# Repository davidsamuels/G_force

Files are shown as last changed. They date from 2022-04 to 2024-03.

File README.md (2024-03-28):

# G_force : repository of my passion project involving microcontrollers and motorsports

## hardware chart
prototype | status | notes | picture |
---|---|---| --- | 
version 0 | done | proof of concept in C with arduino dev board | 
version 1 | done | directionality and RGB in C with arduino dev board |
version 2 | done | switching to rasperby pi rp2040  dev board due to chip shortage. Code still being ported. Partial PCB done with manufacturing files and tested |     
version 3| IP | custom PCB with all components. Switching to Esp32 ecosystem due to wifi/BT |  

*prototype version 1 hardware shown below*
---

Acceleration high point of view.

https://user-images.githubusercontent.com/15238565/163253612-991ed954-f6e4-438f-9013-d2a51dcb510f.mp4

Acceleration gauge cluster point of view.
**note colors are not getting picked up by the gopro well**. Look at the 12 and 6 positions on display to see readout.

https://user-images.githubusercontent.com/15238565/163262918-7c1ad50d-a557-4db1-85e5-fd604fd82128.mp4

Demo code showing the crosshair display.

party_mode

Still image of crosshair display



PCB layout screenshot.


3D render of prototype hardware v2


3D render of prototype hardware v3

Back side view


Schematic v3


Layout v3


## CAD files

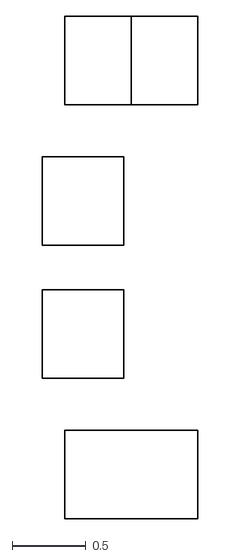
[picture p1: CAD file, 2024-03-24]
gforce_esp32/custom_parts/b3dq_pads.dxf
1.05 x 3.40

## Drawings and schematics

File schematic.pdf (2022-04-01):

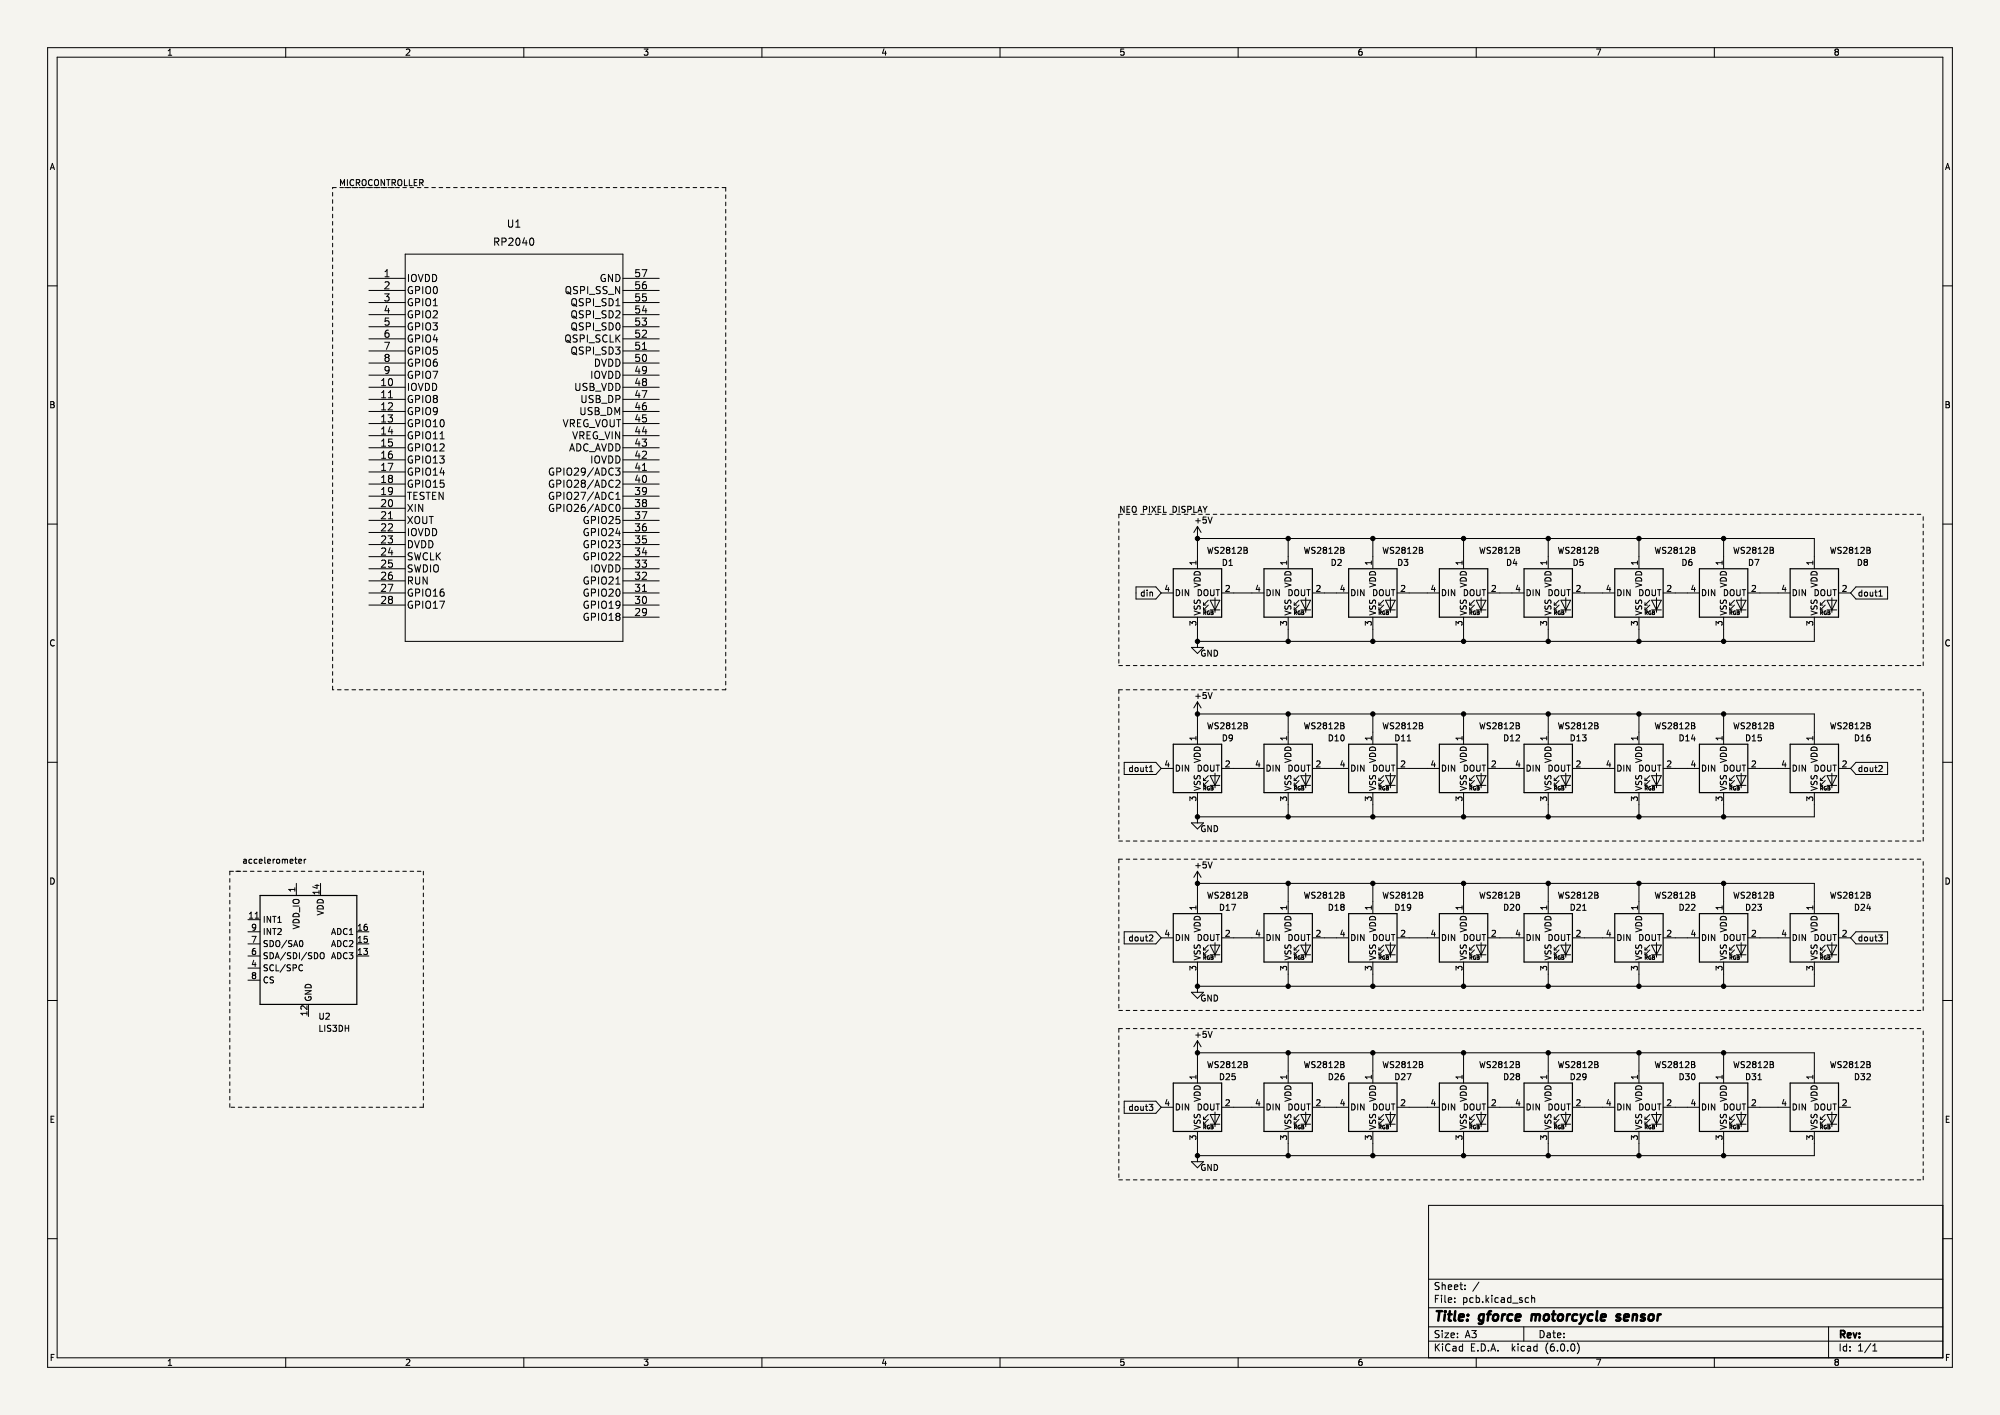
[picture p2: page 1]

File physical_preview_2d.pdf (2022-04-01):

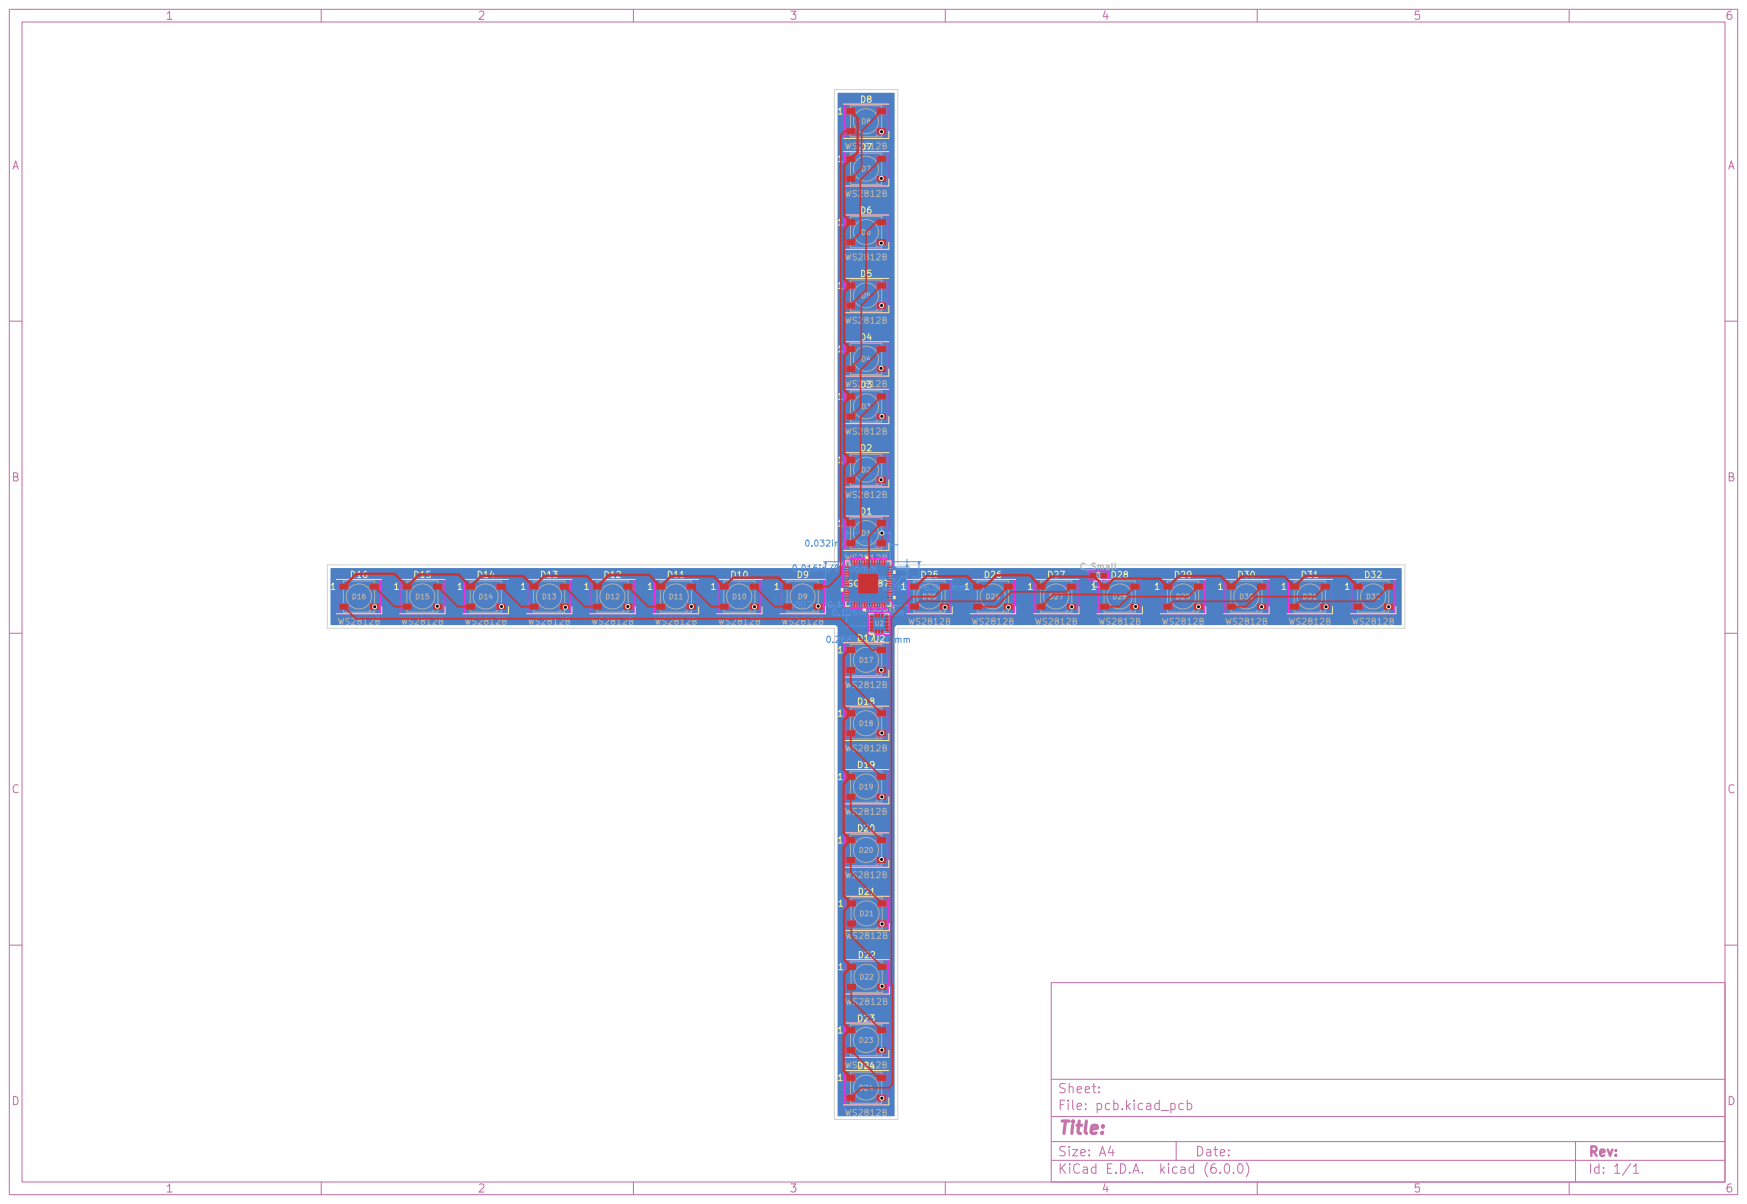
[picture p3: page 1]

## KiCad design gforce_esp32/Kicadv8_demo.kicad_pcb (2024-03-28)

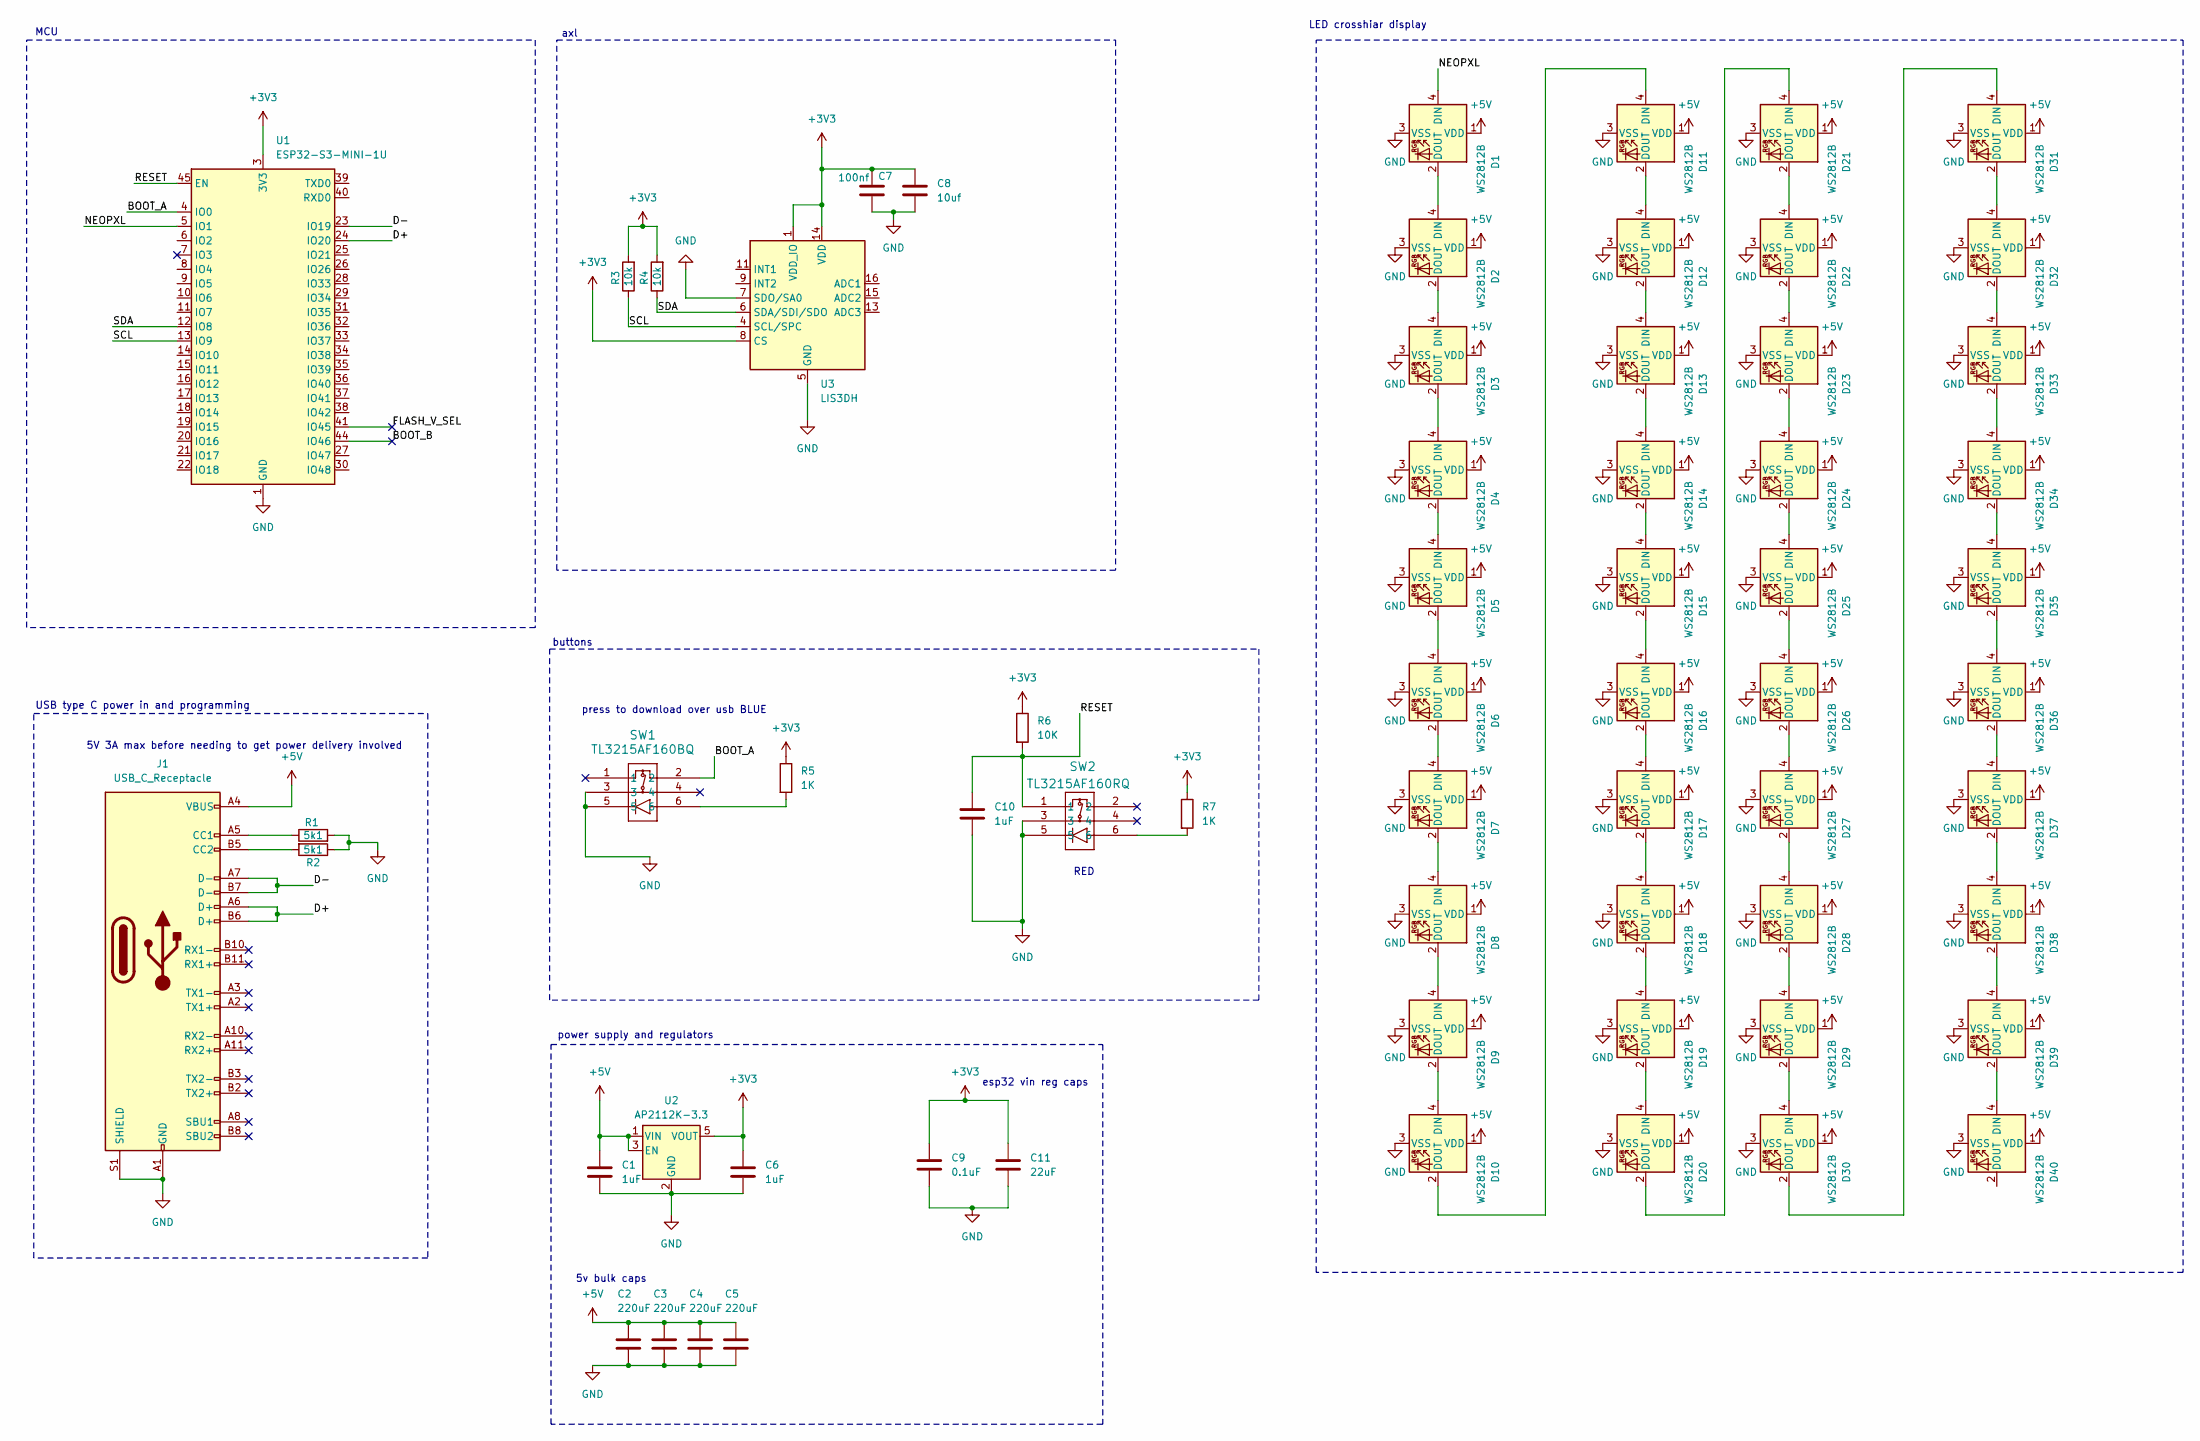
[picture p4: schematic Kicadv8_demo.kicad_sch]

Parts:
C1, C6, C10: 1uF; C_0603_1608Metric
C2, C3, C4, C5: 220uF; C_1206_3216Metric
C7: 100nf; C_0402_1005Metric
C8: 10uf; C_0805_2012Metric
C9: 0.1uF; C_0603_1608Metric
C11: 22uF; C_0603_1608Metric
D1, D2, D3, D4, D5, D6, D7, D8, D9, D10, D11, D12, D13, D14, D15, D16, D17, D18, D19, D20, D21, D22, D23, D24, D25, D26, D27, D28, D29, D30, D31, D32, D33, D34, D35, D36, D37, D38, D39, D40: WS2812B; LED_WS2812B_PLCC4_5.0x5.0mm_P3.2mm; LCSC Part Number C2761795
J1: USB_C_Receptacle; USB_C_Receptacle_Molex_105450-0101
R1, R2: 5k1; R_0603_1608Metric
R3, R4: 10k; R_0603_1608Metric
R5, R7: 1K; R_0603_1608Metric
R6: 10K; R_0603_1608Metric
SW1: TL3215AF160BQ; TL3215AF160BQ_EWI
SW2: TL3215AF160RQ; TL3215AF160BQ_EWI
U1: ESP32-S3-MINI-1U; ESP32-S2-MINI-1U
U2: AP2112K-3.3; SOT-23-5
U3: LIS3DH; LGA-16_3x3mm_P0.5mm_LayoutBorder3x5y

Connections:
+3V3: C6.1, C7.1, C8.1, C9.1, C11.1, R3.2, R4.2, R5.1, R6.1, R7.1, U1.3 (3V3), U2.5 (VOUT), U3.1 (VDD_IO), U3.8 (CS), U3.14 (VDD)
+5V: C1.1, C2.1, C3.1, C4.1, C5.1, D1.1 (VDD), D2.1 (VDD), D3.1 (VDD), D4.1 (VDD), D5.1 (VDD), D6.1 (VDD), D7.1 (VDD), D8.1 (VDD), D9.1 (VDD), D10.1 (VDD), D11.1 (VDD), D12.1 (VDD), D13.1 (VDD), D14.1 (VDD), D15.1 (VDD), D16.1 (VDD), D17.1 (VDD), D18.1 (VDD), D19.1 (VDD), D20.1 (VDD), D21.1 (VDD), D22.1 (VDD), D23.1 (VDD), D24.1 (VDD), D25.1 (VDD), D26.1 (VDD), D27.1 (VDD), D28.1 (VDD), D29.1 (VDD), D30.1 (VDD), D31.1 (VDD), D32.1 (VDD), D33.1 (VDD), D34.1 (VDD), D35.1 (VDD), D36.1 (VDD), D37.1 (VDD), D38.1 (VDD), D39.1 (VDD), D40.1 (VDD), J1.A4 (VBUS), J1.A9 (VBUS), J1.B4 (VBUS), J1.B9 (VBUS), U2.1 (VIN), U2.3 (EN)
/BOOT_A: SW1.2, U1.4 (IO0)
/BOOT_B: U1.44 (IO46)
/D+: J1.A6 (D+), J1.B6 (D+), U1.24 (IO20)
/D-: J1.A7 (D-), J1.B7 (D-), U1.23 (IO19)
/FLASH_V_SEL: U1.41 (IO45)
/NEOPXL: D1.4 (DIN), U1.5 (IO1)
/RESET: C10.1, R6.2, SW2.1, U1.45 (EN)
/SCL: R3.1, U1.13 (IO9), U3.4 (SCL/SPC)
/SDA: R4.1, U1.12 (IO8), U3.6 (SDA/SDI/SDO)
GND: C1.2, C2.2, C3.2, C4.2, C5.2, C6.2, C7.2, C8.2, C9.2, C10.2, C11.2, D1.3 (VSS), D2.3 (VSS), D3.3 (VSS), D4.3 (VSS), D5.3 (VSS), D6.3 (VSS), D7.3 (VSS), D8.3 (VSS), D9.3 (VSS), D10.3 (VSS), D11.3 (VSS), D12.3 (VSS), D13.3 (VSS), D14.3 (VSS), D15.3 (VSS), D16.3 (VSS), D17.3 (VSS), D18.3 (VSS), D19.3 (VSS), D20.3 (VSS), D21.3 (VSS), D22.3 (VSS), D23.3 (VSS), D24.3 (VSS), D25.3 (VSS), D26.3 (VSS), D27.3 (VSS), D28.3 (VSS), D29.3 (VSS), D30.3 (VSS), D31.3 (VSS), D32.3 (VSS), D33.3 (VSS), D34.3 (VSS), D35.3 (VSS), D36.3 (VSS), D37.3 (VSS), D38.3 (VSS), D39.3 (VSS), D40.3 (VSS), J1.A1 (GND), J1.A12 (GND), J1.B1 (GND), J1.B12 (GND), J1.S1 (SHIELD), R1.2, R2.1, SW1.3, SW1.5, SW2.3, SW2.5, U1.1 (GND), U1.2 (GND), U1.42 (GND), U1.43 (GND), U1.46 (GND), U1.47 (GND), U1.48 (GND), U1.49 (GND), U1.50 (GND), U1.51 (GND), U1.52 (GND), U1.53 (GND), U1.54 (GND), U1.55 (GND), U1.56 (GND), U1.57 (GND), U1.58 (GND), U1.59 (GND), U1.60 (GND), U1.61 (GND), U1.62 (GND), U1.63 (GND), U1.64 (GND), U1.65 (GND), U2.2 (GND), U3.5 (GND), U3.7 (SDO/SA0), U3.10 (GND), U3.12 (GND)
unnamed: D1.2 (DOUT), D2.4 (DIN)
unnamed: D2.2 (DOUT), D3.4 (DIN)
unnamed: D3.2 (DOUT), D4.4 (DIN)
unnamed: D4.2 (DOUT), D5.4 (DIN)
unnamed: D5.2 (DOUT), D6.4 (DIN)
unnamed: D6.2 (DOUT), D7.4 (DIN)
unnamed: D7.2 (DOUT), D8.4 (DIN)
unnamed: D8.2 (DOUT), D9.4 (DIN)
unnamed: D9.2 (DOUT), D10.4 (DIN)
unnamed: D10.2 (DOUT), D11.4 (DIN)
unnamed: D11.2 (DOUT), D12.4 (DIN)
unnamed: D12.2 (DOUT), D13.4 (DIN)
unnamed: D13.2 (DOUT), D14.4 (DIN)
unnamed: D14.2 (DOUT), D15.4 (DIN)
unnamed: D15.2 (DOUT), D16.4 (DIN)
unnamed: D16.2 (DOUT), D17.4 (DIN)
unnamed: D17.2 (DOUT), D18.4 (DIN)
unnamed: D18.2 (DOUT), D19.4 (DIN)
unnamed: D19.2 (DOUT), D20.4 (DIN)
unnamed: D20.2 (DOUT), D21.4 (DIN)
unnamed: D21.2 (DOUT), D22.4 (DIN)
unnamed: D22.2 (DOUT), D23.4 (DIN)
unnamed: D23.2 (DOUT), D24.4 (DIN)
unnamed: D24.2 (DOUT), D25.4 (DIN)
unnamed: D25.2 (DOUT), D26.4 (DIN)
unnamed: D26.2 (DOUT), D27.4 (DIN)
unnamed: D27.2 (DOUT), D28.4 (DIN)
unnamed: D28.2 (DOUT), D29.4 (DIN)
unnamed: D29.2 (DOUT), D30.4 (DIN)
unnamed: D30.2 (DOUT), D31.4 (DIN)
unnamed: D31.2 (DOUT), D32.4 (DIN)
unnamed: D32.2 (DOUT), D33.4 (DIN)
unnamed: D33.2 (DOUT), D34.4 (DIN)
unnamed: D34.2 (DOUT), D35.4 (DIN)
unnamed: D35.2 (DOUT), D36.4 (DIN)
unnamed: D36.2 (DOUT), D37.4 (DIN)
unnamed: D37.2 (DOUT), D38.4 (DIN)
unnamed: D38.2 (DOUT), D39.4 (DIN)
unnamed: D39.2 (DOUT), D40.4 (DIN)
unnamed: J1.A5 (CC1), R1.1
unnamed: J1.B5 (CC2), R2.2
unnamed: R5.2, SW1.6
unnamed: R7.2, SW2.6

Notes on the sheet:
5v bulk caps
5V 3A max before needing to get power delivery involved
RED
power supply and regulators
axl
MCU
esp32 vin reg caps
LED crosshiar display
buttons
USB type C power in and programming
press to download over usb BLUE

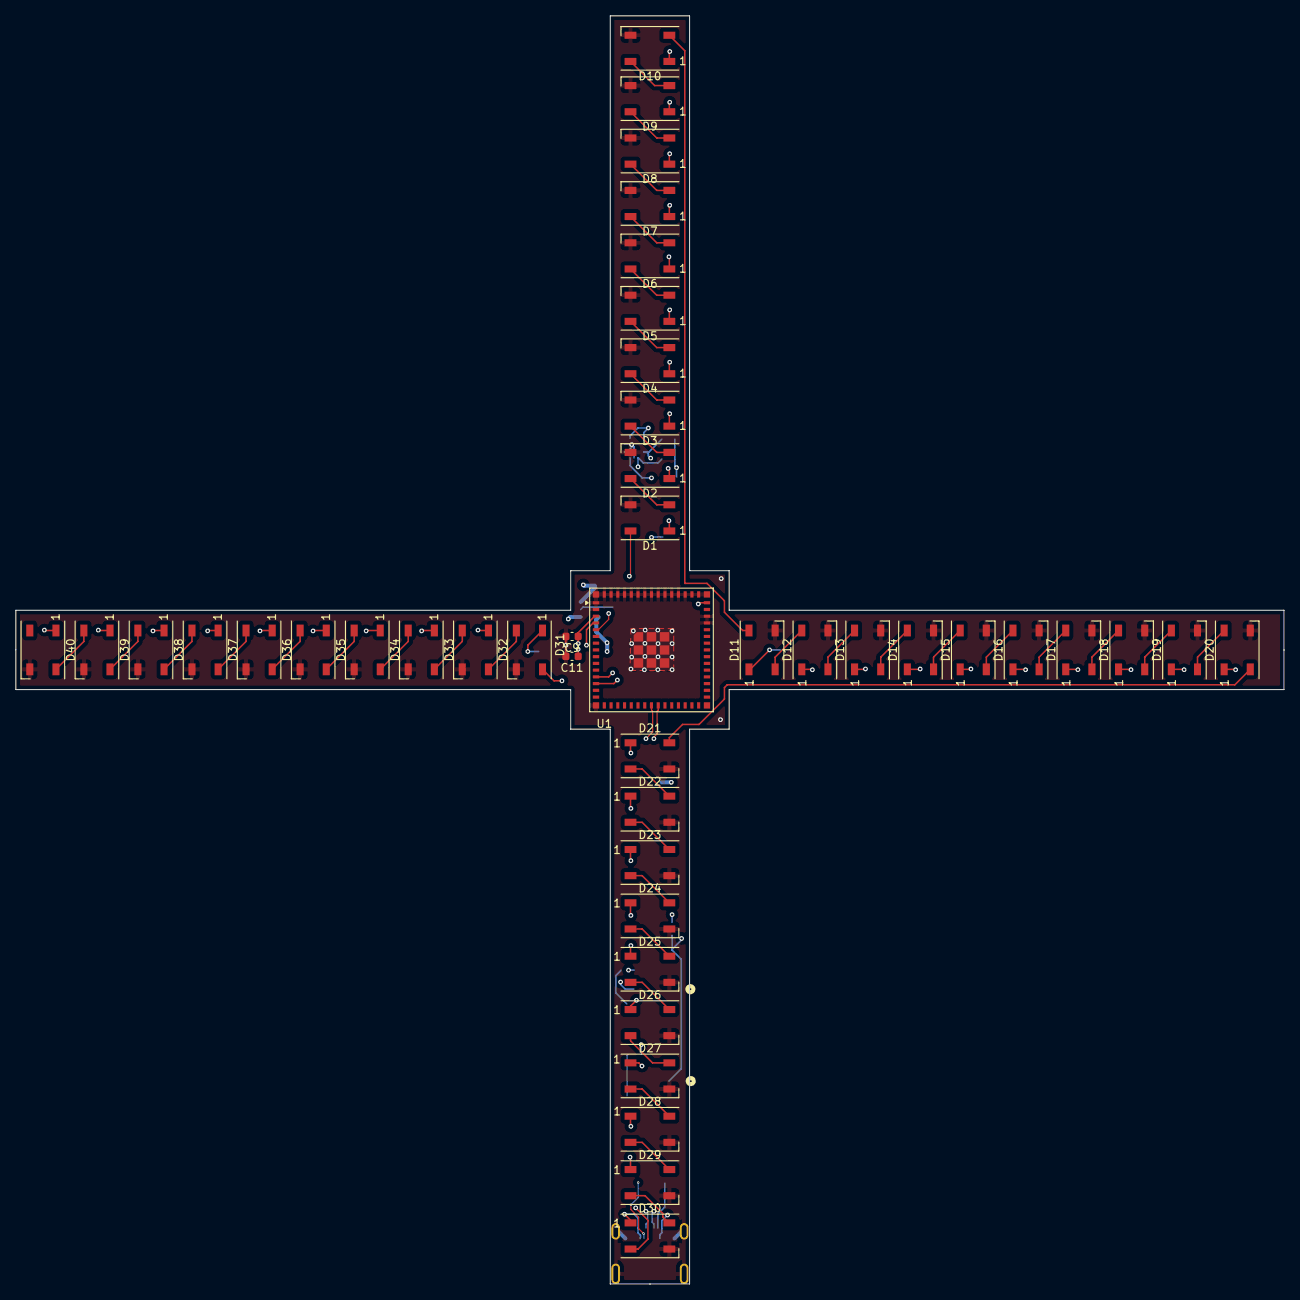
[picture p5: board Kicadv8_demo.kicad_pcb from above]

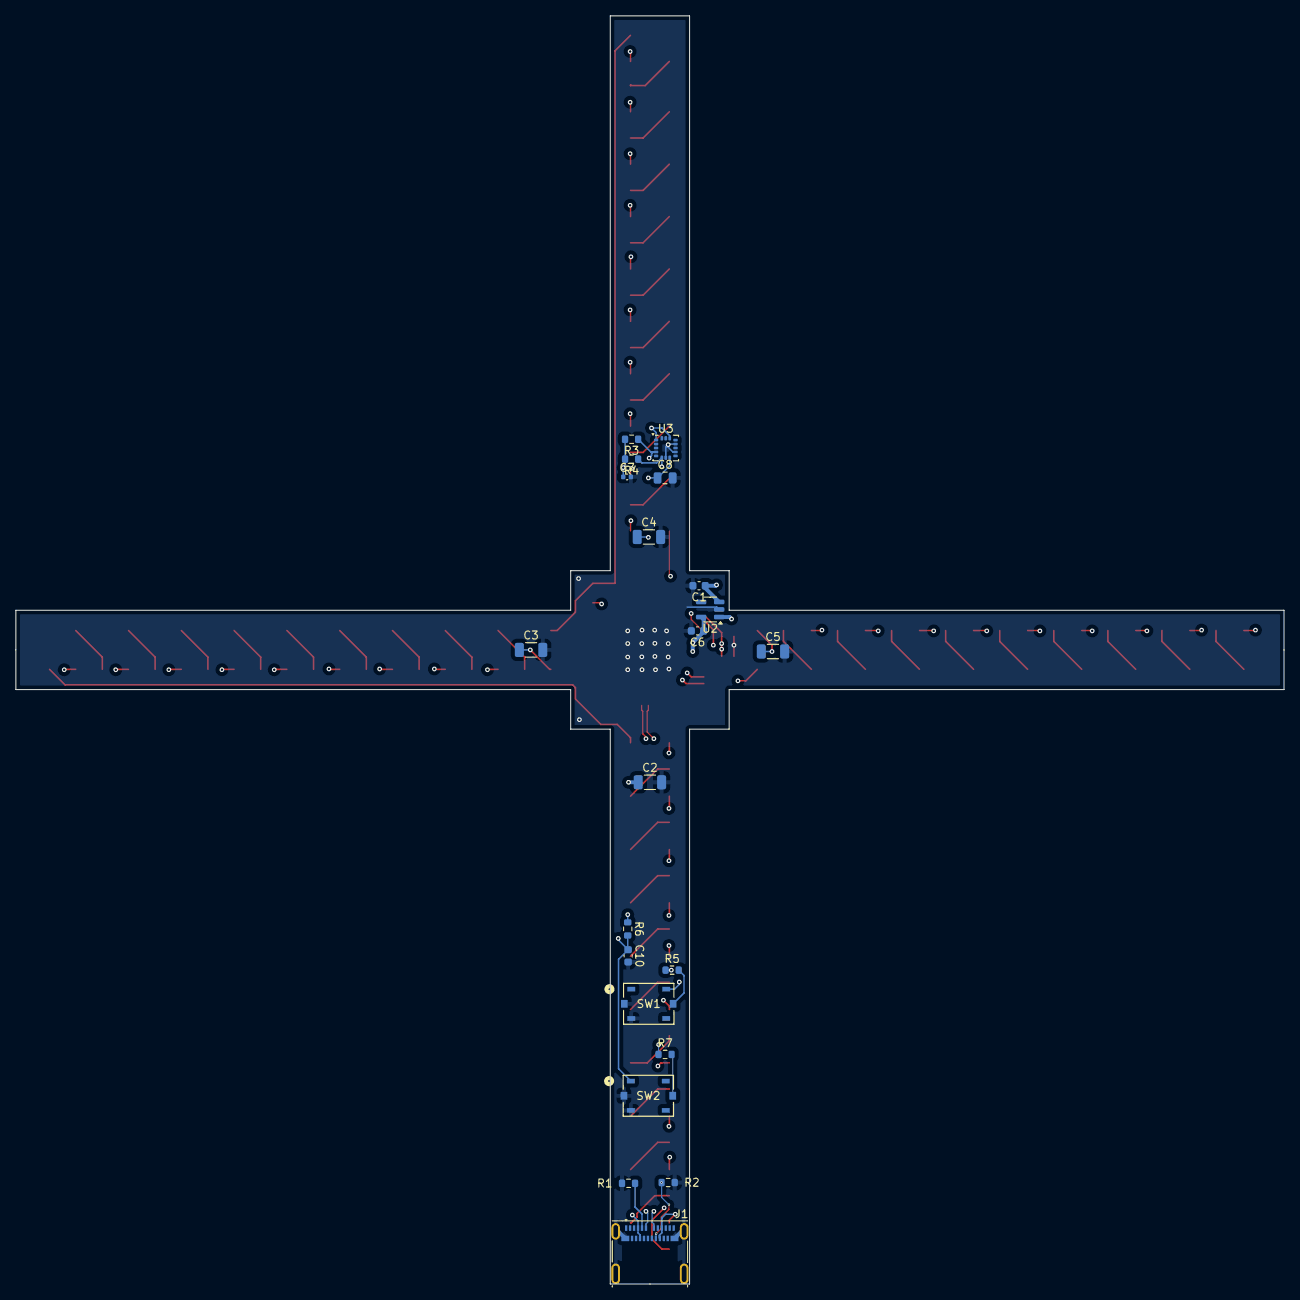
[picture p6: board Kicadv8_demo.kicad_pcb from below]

Board: 8 copper layers, 160.0 x 160.0 mm, 64 parts (21 on the bottom side), 53 nets.

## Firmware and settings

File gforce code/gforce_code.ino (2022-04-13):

#include <Arduino_LSM6DS3.h>   // lib for inertial measuerment unit built into arduino iot 33 board
#include <Adafruit_NeoPixel.h> //lib for led strip

#define PIN  2     //pin the rgb strip is connected to
#define NumPixel 32 //  4 pairs of 8led strips
Adafruit_NeoPixel strip = Adafruit_NeoPixel(NumPixel, PIN, NEO_GRB + NEO_KHZ800);
void setup()
{
  // put your setup code here, to run once:
  strip.begin();
  strip.setBrightness(20);
  strip.show();

  pinMode(12, INPUT_PULLUP); //BUTTON
  pinMode(10, OUTPUT);       // EFFECTIVLY SWITCHABLE GROUND
  digitalWrite(10, LOW);     //GROUND THE BUTON

  Serial.begin(9600);
  //while (!Serial);

  if (!IMU.begin())
  {
    Serial.println("Failed to initialize IMU!");
    while (1);
      
  }
}

float fxcur, fycur, fzcur, fxzero, fyzero, fzzero, fxcal, fycal, fzcal; // float varibles to hold accelorometer data

void loop()
{
  smoothData();
  if (digitalRead(12) == 0) //cal button
    calibration();

  offsetCorrection();
  lit();
  
}

float smoothData()
{
  float x, y, z; // temporary varibles to hold data for averaging/smoothing data
  float sumx = 0, sumy = 0 ; 
  float avex = 0, avey = 0;
  int smoothSize = 8; //bigger the num the stronger the effect and slower the calculation

  for (int i = 0; i < smoothSize; i++)
  {
    while (IMU.accelerationAvailable() == 0)
    {
      //Serial.println("waiting for data ");
    }
    IMU.readAcceleration(x, y, z);
    sumx = sumx + x;
    sumy = sumy + y;
  }

  fxcur = sumx / (float)smoothSize;
  fycur = sumy / (float)smoothSize;
  Serial.println("fxcur ");
  Serial.println(fxcur);
  Serial.println("fycur ");
  Serial.println(fycur);
}

void calibration() //after this function is called we have calibrated values to work with
{
  //Serial.println("button pressed zeroing sensor");
  IMU.readAcceleration(fxzero, fyzero, fzzero);
}

void offsetCorrection()
{
  fxcal = fxcur - fxzero;
  fycal = fycur - fyzero;
  //if fxcal > 1 , fxcal = 1
  Serial.println("fxcal ");
  Serial.println(fxcal);
  Serial.println("fycal ");
  Serial.println(fycal);
}

void lit()
{
  strip.fill(strip.Color(0,0,0),0,0); //erase strip
  if (fycal > 0) //leds [0-7]
  {
    //need to think how to select within range
    for(int yptmp = 0 ; yptmp < (int)(fycal*8); yptmp++)
    {
      strip.setPixelColor(yptmp,strip.ColorHSV(10000*yptmp+1000,255,255));
    }
    strip.setPixelColor((int)(fycal*8),255,0,0);
    Serial.println("posistion y+ ");
    Serial.println((fycal*8));
  }
  else //leds [16-23]
  {
    for(int yptmp = 16 ; yptmp < (int)(-fycal*8)+16; yptmp++)
    {
      strip.setPixelColor(yptmp,strip.ColorHSV(10000*yptmp+1000,255,255));
    }
    strip.setPixelColor((int)(-fycal*8)+16,255,0,0);
    Serial.println("posistion y- ");
    Serial.println((-fycal*8)+16);
  }

  if (fxcal > 0) //leds[24-31]
  {
     for(int xptmp = 24 ; xptmp < (int)(fxcal*8)+24; xptmp++)
    {
      strip.setPixelColor(xptmp,strip.ColorHSV(10000*xptmp+1000,255,255));
    }
    strip.setPixelColor((int)(fxcal*8)+24,255,0,0);
    Serial.println("posistion x+ ");
    Serial.println((fxcal*8)+8);

  }
  else //leds[8-15]
  {
    for(int xptmp = 8 ; xptmp < (int)(-fxcal*8)+8 ; xptmp++)
    {
      strip.setPixelColor(xptmp,strip.ColorHSV(10000*xptmp+1000,255,255));
    }
    strip.setPixelColor((int)(-fxcal*8)+8,255,0,0);
    Serial.println("posistion x- ");
    Serial.println((-fxcal*8)+25);
  }
  Serial.println("\n \n sending values to display ");
  strip.show();
}

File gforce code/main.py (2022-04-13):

#https://github.com/tinypico/tinypico-micropython/tree/master/lis3dh%20library

import machine, neopixel, time, lis3dh
np = neopixel.NeoPixel(machine.Pin(4),8)
np[0] = (50,50,50)
np.write()

i2c = machine.I2C(1, scl = machine.Pin(3), sda = machine.Pin(2))

devices = i2c.scan()

if devices:
    for d in devices:
        print(hex(d))
        
imu = lis3dh.LIS3DH_I2C(i2c)

if imu.device_check():
    imu.range = lis3dh.RANGE_2_G
    print("we found the device")
    
while True:
    x,y,z = [value / lis3dh.STANDARD_GRAVITY for value in imu.acceleration]
    print("x = %0.3f G, y = %0.3f G, z= %0.3f G" % (x,y,z))
    time.sleep(0.01)
    



"""
ctrl_reg1 = 0b10010111 #run at 1.250 Khz with xyz axis enabled no low power
ctrl_reg4 = 0b00000000

i2c.writeto_mem(0x18,0x20,hex(ctrl_reg1)) #slave id , slav reg id, message
i2c.writeto_mem(0x18,0x23,hex(ctrl_reg4))
ready = i2c.readfrom_mem(0x18,0x27,1)
accel_data1 = i2c.readfrom_mem(0x18,0x28,1)
accel_data2 = i2c.readfrom_mem(0x18,0x29,1)

print("ready",ready)
print("xl",accel_data1)
print("xh",accel_data2)
"""

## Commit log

2022-04-13 adding pcb and code files
    [quick_rp2040_proto.kicad_pcb, quick_rp2040_proto.kicad_sch]
2022-04-14 added pic of pcb layout
2024-03-24 adding next version of gforce files
    kicad 8 pcb, switching to esp32 mcu
    [Kicadv8_demo.kicad_pcb, Kicadv8_demo.kicad_sch, b3dq_pads.dxf]
2024-03-24 gforce_esp32 is newest
    added 3d footprint of mcu
    [Kicadv8_demo.kicad_pcb, Kicadv8_demo.kicad_sch]
2024-03-25 usb diff pair needs updated
    [Kicadv8_demo.kicad_pcb]
2024-03-25 layout placing parts
    lined up leds
    [Kicadv8_demo.kicad_pcb, Kicadv8_demo.kicad_sch]
2024-03-26 SCHEMATIC LEDS MAPPED. FAB NOTES ADDED
    [Kicadv8_demo.kicad_pcb, Kicadv8_demo.kicad_sch]
2024-03-27 some net pours and routing
    [Kicadv8_demo.kicad_pcb]
2024-03-27 most important traces started to route
    [Kicadv8_demo.kicad_pcb]
2024-03-28 all routing done
    [Kicadv8_demo.kicad_pcb]
